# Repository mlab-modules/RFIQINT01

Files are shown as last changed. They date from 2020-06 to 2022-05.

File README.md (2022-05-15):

# RFIQINT01B - RF signal I/Q interface

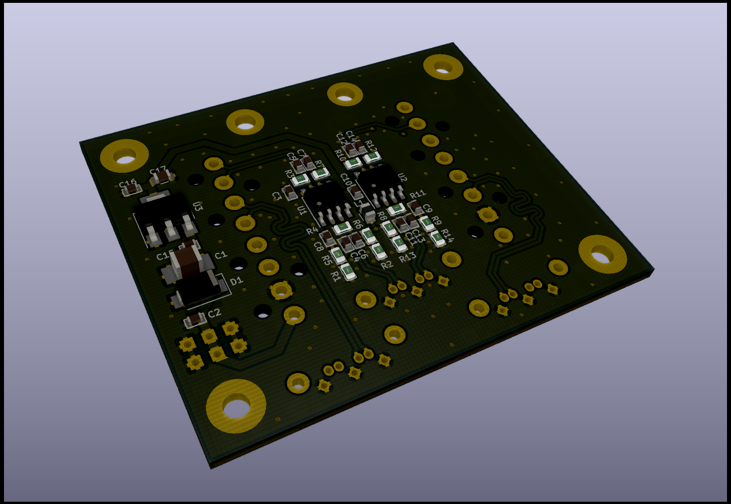
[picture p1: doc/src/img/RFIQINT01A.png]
RFIQINT01B PCB render


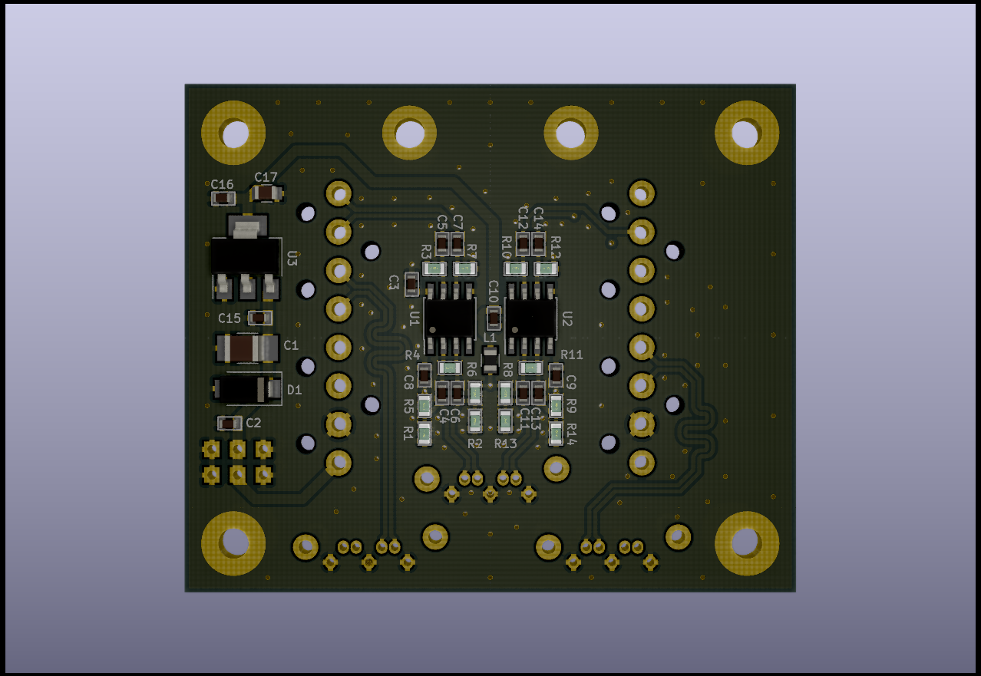
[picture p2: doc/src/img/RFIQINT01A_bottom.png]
RFIQINT01B PCB render


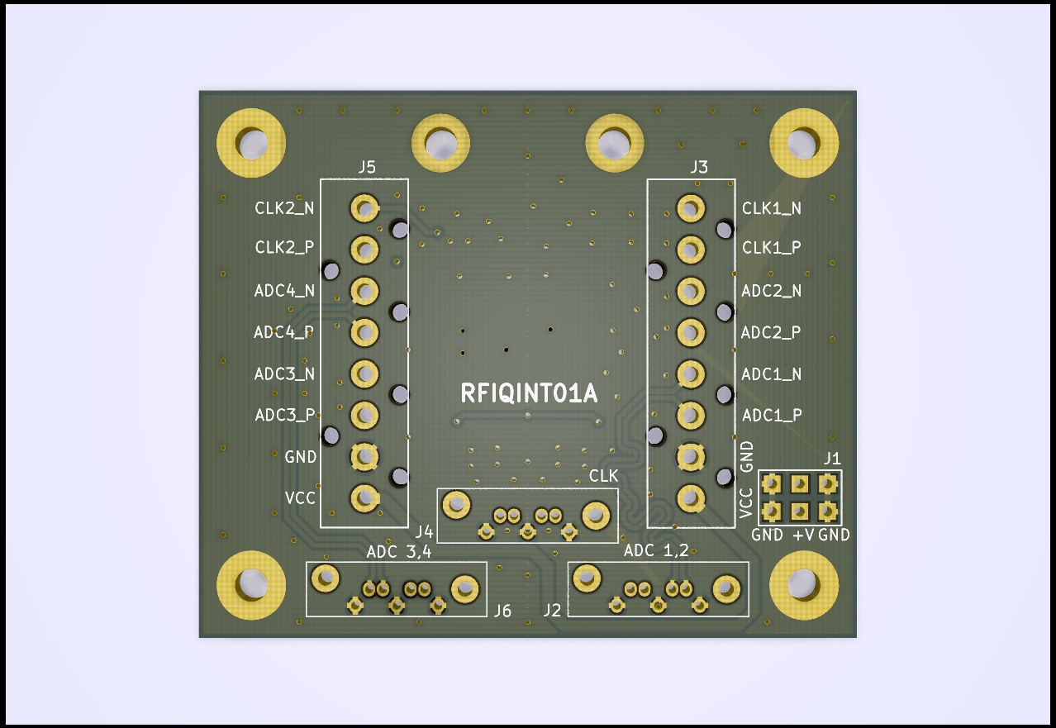
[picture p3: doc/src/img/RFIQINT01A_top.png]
RFIQINT01B PCB render


## Parameters

| Parameter | Value | Description |
|---|---|---|
| Frequency range | 100 - 1000 MHz |  |
| Interface | RJ45 | CAT 7/A cable is expected |
| Operating and storage temperature | -20 - +30°C |  |
| Operational input voltage for Antenna | 9 - 12 V |  |
| Operational input voltage  | 3.3-3.6 V | 130 mA for LO buffer core |

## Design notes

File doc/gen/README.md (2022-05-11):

# PCB

Board size: 60.45x50.29 mm (2.38x1.98 inches)

- This is the size of the rectangle that contains the board
- Thickness: 1.6 mm (63 mils)
- Material: FR4
- Finish: None
- Layers: 2
- Copper thickness: 35 µm

Solder mask: TOP / BOTTOM

- Color: Green

Silk screen: TOP / BOTTOM

- Color: White

Stackup:

| Name | Type | Color | Thickness | Material | Epsilon_r | Loss tangent |
|---|---|---|---|---|---|---|
| F.SilkS | Top Silk Screen | | | | | |
| F.Paste | Top Solder Paste | | | | | |
| F.Mask | Top Solder Mask | | 10 | | | |
| F.Cu | copper | | 35 | | | |
| dielectric 1 | core | | 1510 | FR4 | 4.5 | 0.02 |
| B.Cu | copper | | 35 | | | |
| B.Mask | Bottom Solder Mask | | 10 | | | |
| B.Paste | Bottom Solder Paste  | | | | | |
| B.SilkS | Bottom Silk Screen | | | | | |

# Important sizes

Clearance: 0.2 mm (8 mils)

Track width: 0.4 mm (16 mils)

- By design rules: 0.2 mm (8 mils)

Drill: 0.4 mm (16 mils)

- Vias: 0.4 mm (16 mils) [Design: 0.3 mm (12 mils)]
- Pads: 0.74 mm (29 mils)

Via: 0.75/0.4 mm (30/16 mils)

- By design rules: 0.4/0.3 mm (16/12 mils)
- Micro via: no [0.2/0.1 mm (8/4 mils)]
- Burried/blind via: no

Outer Annular Ring: 0.35 mm (14 mils)

- By design rules: 0.36 mm (14 mils)

Eurocircuits class: 4C

# General stats

Components count: (SMD/THT)

- Top: 0/6 (THT)
- Bottom: 36/6 (SMD + THT)

Defined tracks:

- 0.2 mm (8 mils)
- 0.3 mm (12 mils)
- 0.4 mm (16 mils)
- 0.5 mm (20 mils)
- 0.6 mm (24 mils)
- 0.7 mm (28 mils)
- 1.0 mm (39 mils)

Used tracks:

- 0.4 mm (16 mils) (562) defined: yes
- 0.6 mm (24 mils) (15) defined: yes
- 1.0 mm (39 mils) (37) defined: yes

Defined vias:

Used vias:

- 0.75/0.4 mm (30/16 mils) (Count: 126, Aspect: 2.1 A) defined: no

Holes (excluding vias):

- 0.74 mm (29 mils) (21)
- 0.89 mm (35 mils) (8)
- 1.35 mm (53 mils) (6)
- 1.4 mm (55 mils) (16)
- 1.6 mm (63 mils) (12)
- 3.0 mm (118 mils) (6)

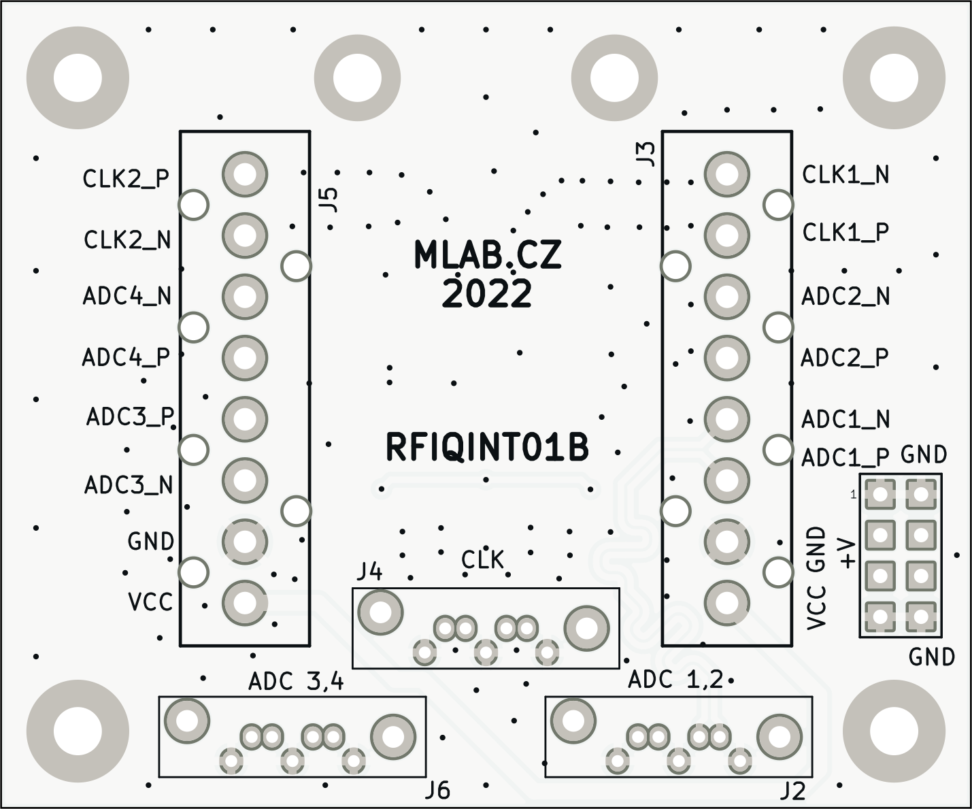
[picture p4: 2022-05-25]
doc/gen/img/RFIQINT01B-top.png

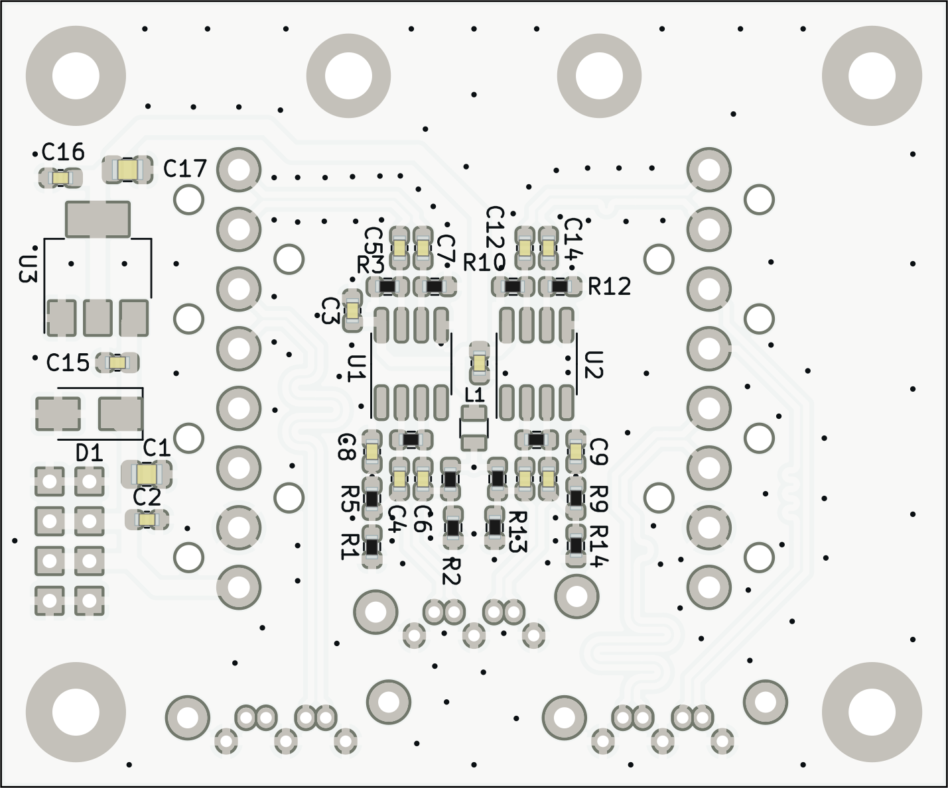
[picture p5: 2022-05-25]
doc/gen/img/RFIQINT01B-bottom.png

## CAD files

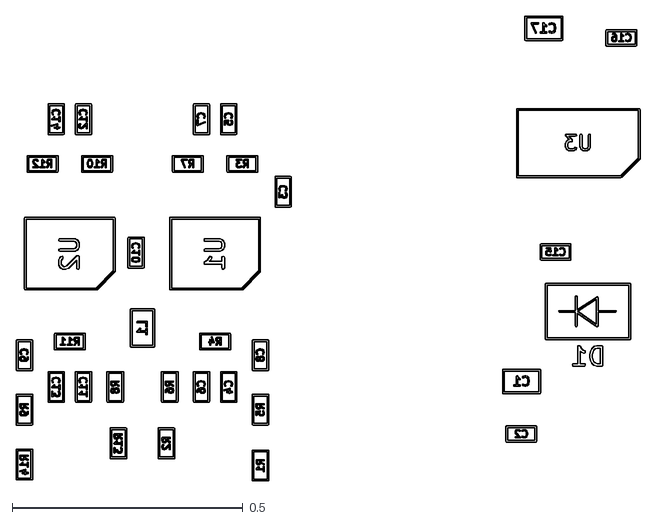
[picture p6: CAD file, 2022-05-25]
doc/gen/dxf/RFIQINT01B-B_Fab.dxf
1.35 x 1.01

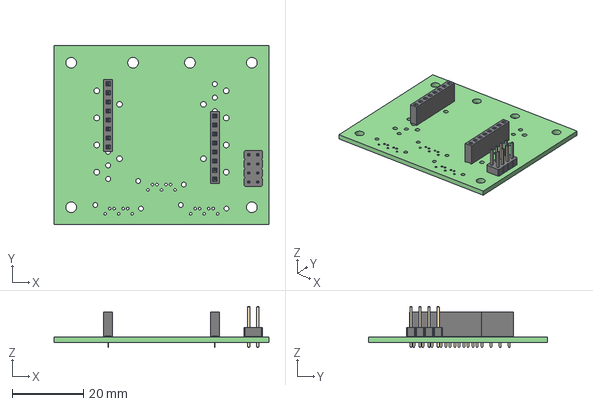
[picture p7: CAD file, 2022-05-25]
doc/gen/RFIQINT01B.step
60.5 x 50.3 x 11.6 mm
tmplr6t_708 PCB

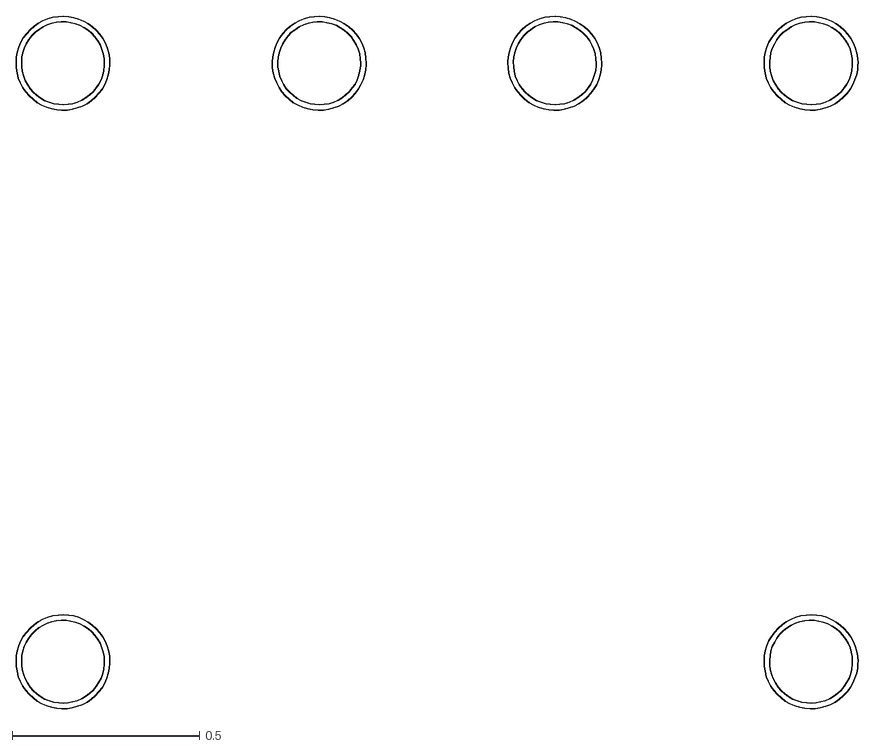
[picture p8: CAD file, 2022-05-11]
doc/gen/dxf/RFIQINT01B-User_Comments.dxf
2.25 x 1.85

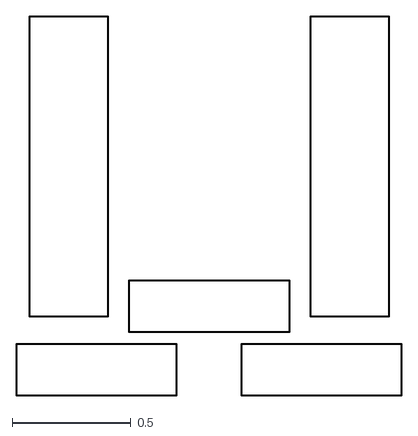
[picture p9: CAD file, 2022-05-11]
doc/gen/dxf/RFIQINT01B-F_Courtyard.dxf
1.62 x 1.59

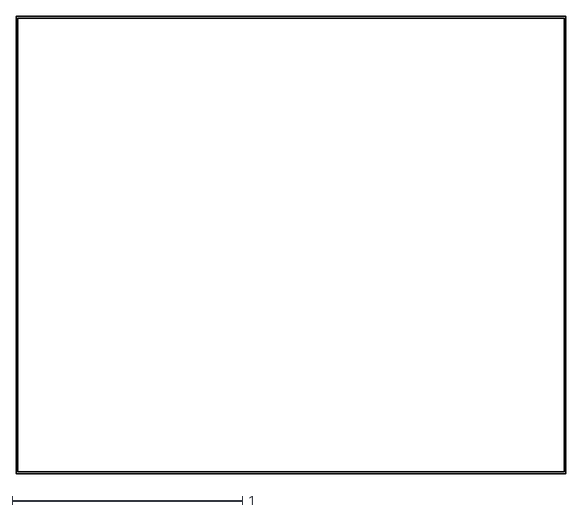
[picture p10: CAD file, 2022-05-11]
doc/gen/dxf/RFIQINT01B-Edge_Cuts.dxf
2.39 x 1.99

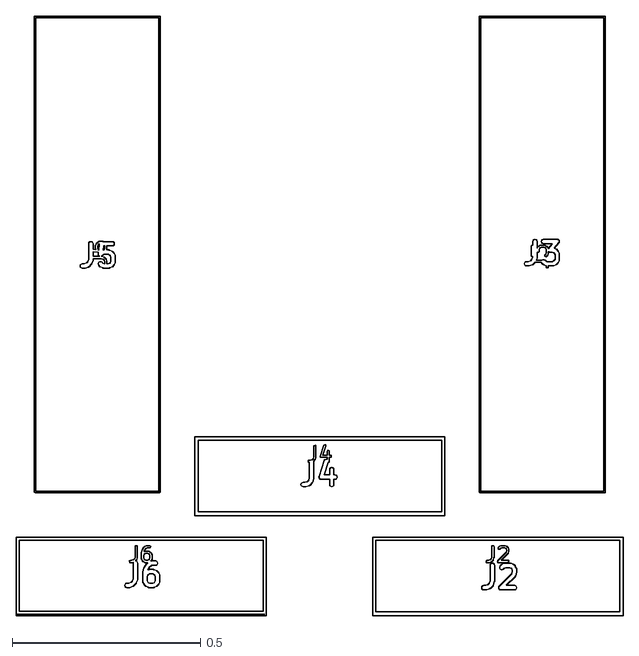
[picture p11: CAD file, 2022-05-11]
doc/gen/dxf/RFIQINT01B-F_Fab.dxf
1.61 x 1.59

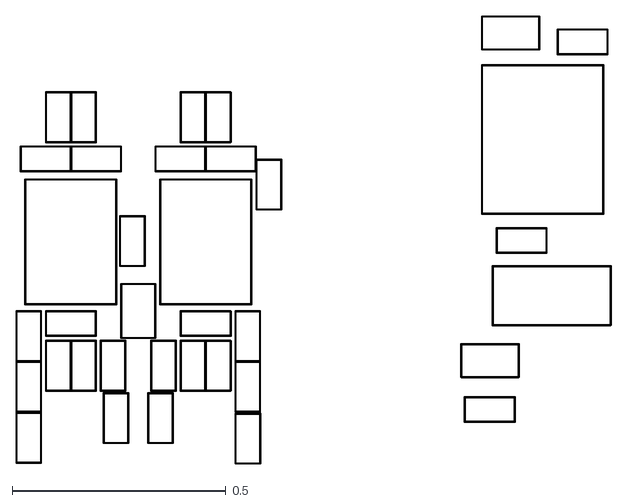
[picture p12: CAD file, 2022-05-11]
doc/gen/dxf/RFIQINT01B-B_Courtyard.dxf
1.39 x 1.05

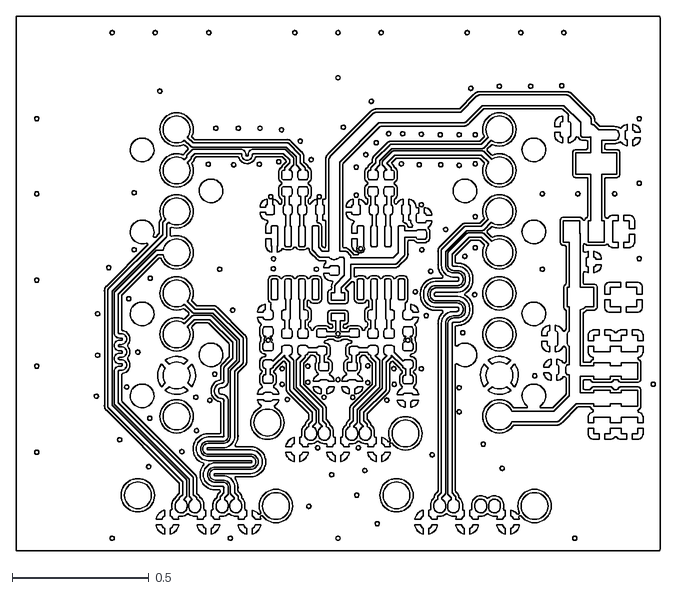
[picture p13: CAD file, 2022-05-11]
doc/gen/dxf/RFIQINT01B-B_Cu.dxf
2.36 x 1.96

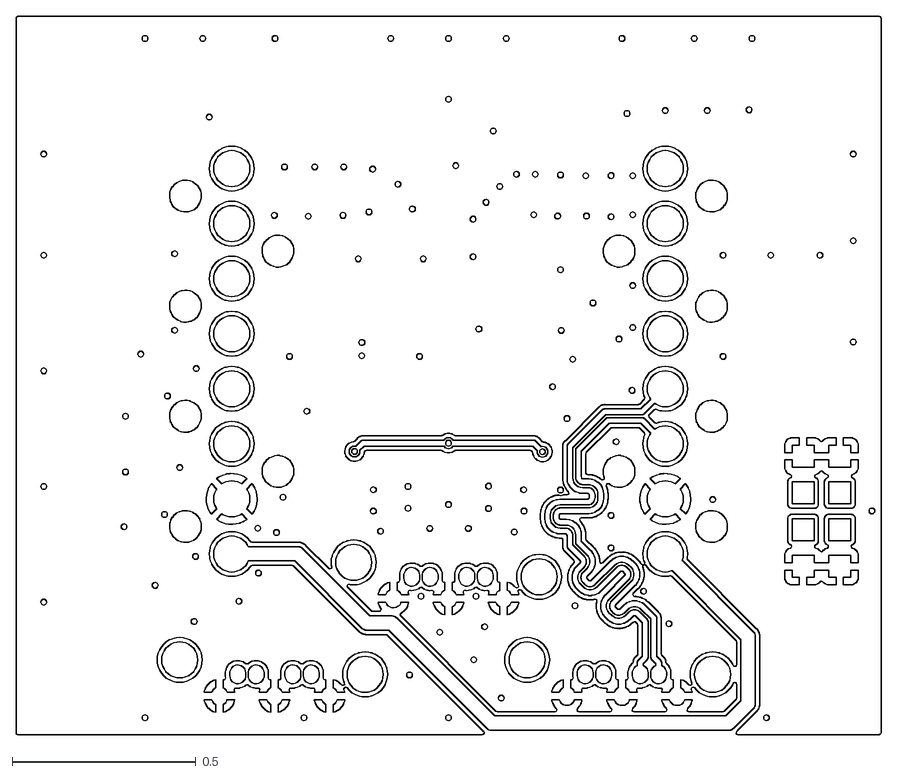
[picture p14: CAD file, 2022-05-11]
doc/gen/dxf/RFIQINT01B-F_Cu.dxf
2.36 x 1.96

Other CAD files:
doc/gen/dxf/RFIQINT01B-F_Adhesive.dxf
doc/gen/dxf/RFIQINT01B-B_Adhesive.dxf
doc/gen/dxf/RFIQINT01B-User_Eco1.dxf
doc/gen/dxf/RFIQINT01B-User_Drawings.dxf
doc/gen/dxf/RFIQINT01B-User_Eco2.dxf
doc/gen/dxf/RFIQINT01B-Margin.dxf
doc/gen/dxf/RFIQINT01B-B_Mask.dxf
doc/gen/dxf/RFIQINT01B-B_Paste.dxf
doc/gen/dxf/RFIQINT01B-B_Silkscreen.dxf
doc/gen/dxf/RFIQINT01B-F_Mask.dxf
doc/gen/dxf/RFIQINT01B-F_Paste.dxf
doc/gen/dxf/RFIQINT01B-F_Silkscreen.dxf

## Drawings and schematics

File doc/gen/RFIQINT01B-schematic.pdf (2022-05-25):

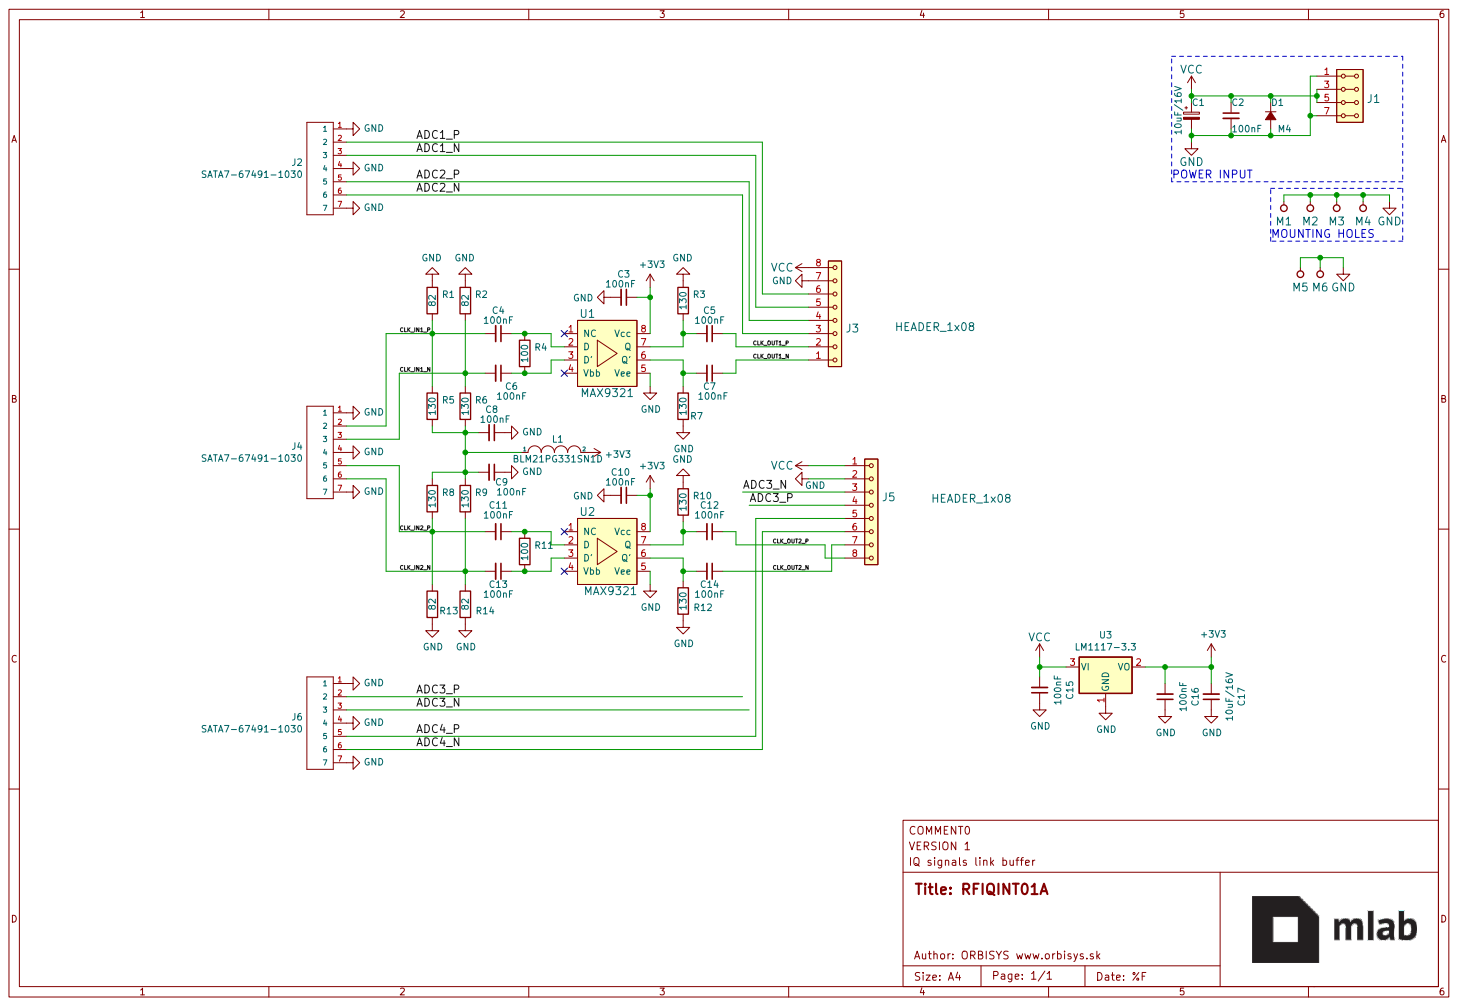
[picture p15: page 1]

COMMENT0 VERSION 1

IQ signals link buffer

Page: 1/1 Date: %F Title: RFIQINT01A | D Author: ORBISYS www.orbisys.sk Size: A4

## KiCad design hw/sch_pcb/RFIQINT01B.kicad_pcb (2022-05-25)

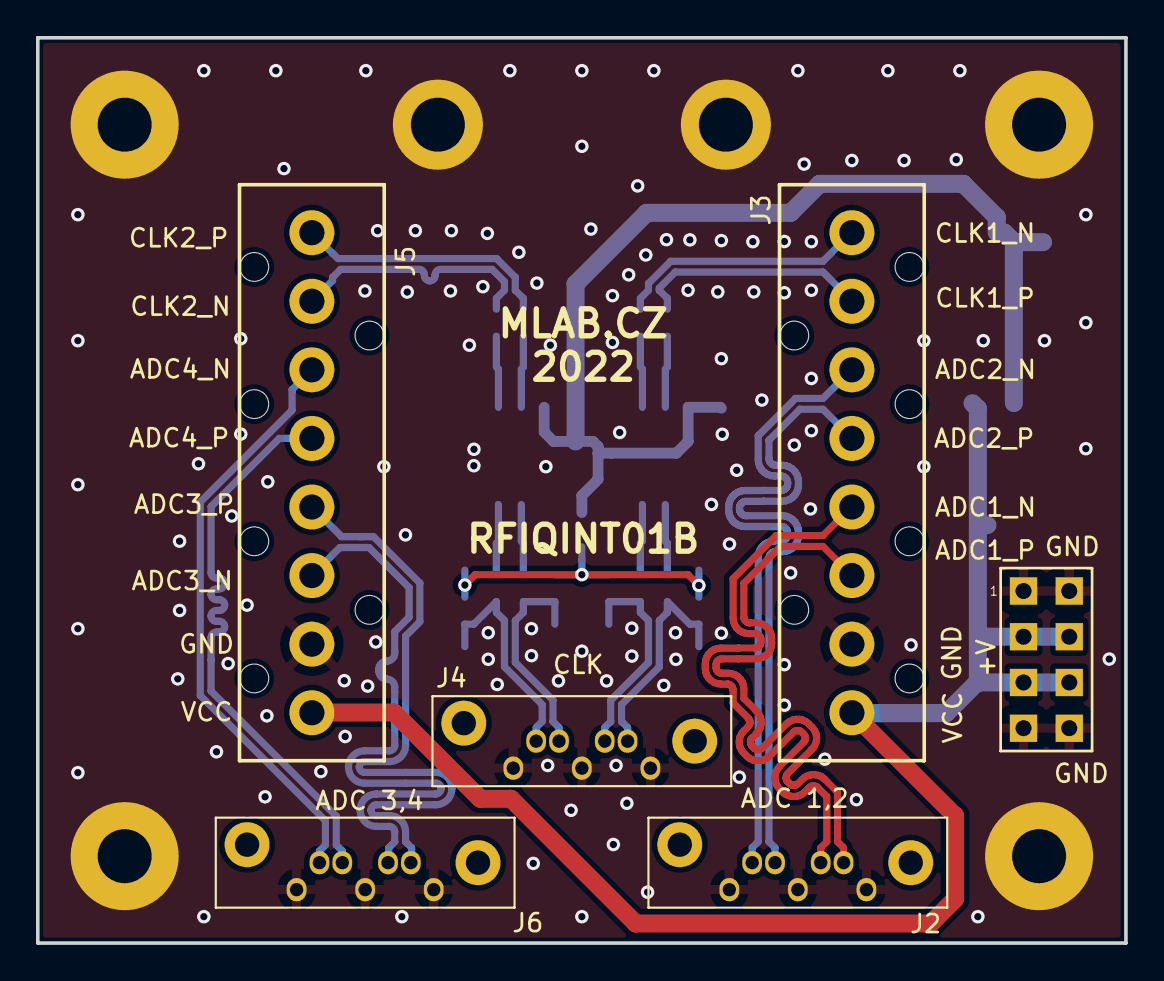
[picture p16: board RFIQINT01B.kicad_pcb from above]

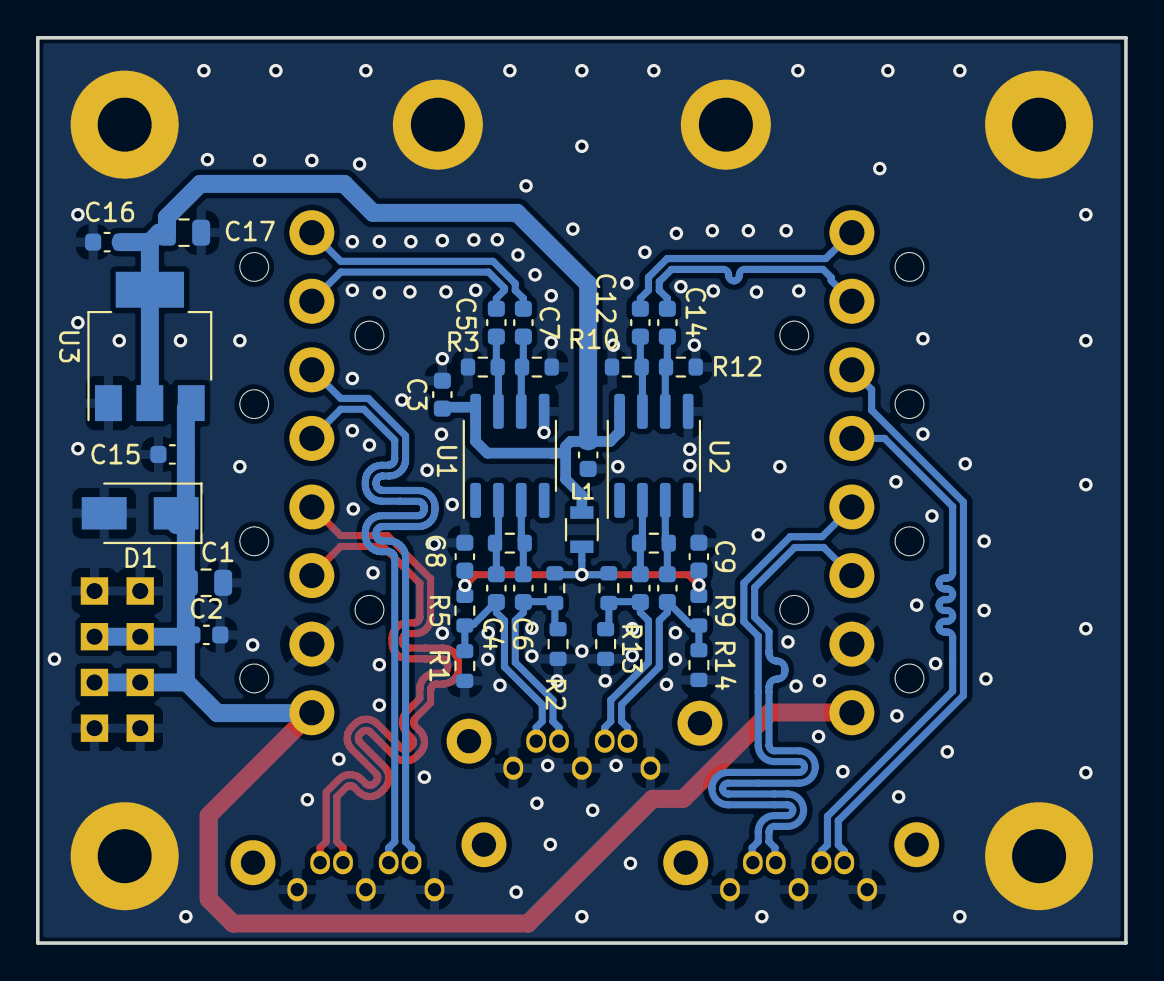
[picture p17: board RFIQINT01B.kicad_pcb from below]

Board: 2 copper layers, 60.5 x 50.3 mm, 48 parts (42 on the bottom side), 28 nets.

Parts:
C1, C17: 10uF/16V; C_0805_2012Metric
C2, C3, C4, C5, C6, C7, C8, C9, C10, C11, C12, C13, C14, C15, C16: 100nF; C_0603_1608Metric
D1: M4; D_SMA
J1: HEADER_2x04_PARALLEL; Straight_2x04
J2, J4, J6: SATA7-67491-1030; SATA-7_THT_VERT_2
J3, J5: HEADER_1x08; IDC381-8-110
L1: BLM21PG331SN1D; L_0805
M1, M2, M3, M4, M5, M6: HOLE; MountingHole_3mm
R1, R2, R13, R14: 82; R_0603_1608Metric
R3, R5, R6, R7, R8, R9, R10, R12: 130; R_0603_1608Metric
R4, R11: 100; R_0603_1608Metric
U1, U2: MAX9321; SOIC-8_3.9x4.9mm_P1.27mm
U3: LM1117-3.3; SOT-223-3_TabPin2

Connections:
+3V3: C3.1, C10.1, C16.2, C17.2, L1.2, U1.8 (Vcc), U2.8 (Vcc), U3.2 (VO)
/ADC1_N: J2.3, J3.5
/ADC1_P: J2.2, J3.6
/ADC2_N: J2.6, J3.3
/ADC2_P: J2.5, J3.4
/ADC3_N: J5.3, J6.3
/ADC3_P: J5.4, J6.2
/ADC4_N: J5.6, J6.6
/ADC4_P: J5.5, J6.5
/CLK_IN1_N: C6.2, J4.3, R2.2, R6.1
/CLK_IN1_P: C4.2, J4.2, R1.2, R5.1
/CLK_IN2_N: C13.2, J4.6, R9.2, R14.1
/CLK_IN2_P: C11.2, J4.5, R8.2, R13.1
/CLK_OUT1_N: C7.1, J3.1
/CLK_OUT1_P: C5.1, J3.2
/CLK_OUT2_N: C14.1, J5.7
/CLK_OUT2_P: C12.1, J5.8
GND: C1.2, C2.2, C3.2, C8.1, C9.1, C10.2, C15.1, C16.1, C17.1, D1.2 (A), J1.1, J1.2, J1.7, J1.8, J2.1, J2.4, J2.7, J3.7, J4.1, J4.4, J4.7, J5.2, J6.1, J6.4, J6.7, M1.1, M2.1, M3.1, M4.1, M5.1, M6.1, R1.1, R2.1, R3.1, R7.2, R10.1, R12.2, R13.2, R14.2, U1.5 (Vee), U2.5 (Vee), U3.1 (GND)
unnamed: C4.1, R4.1, U1.2 (D)
unnamed: C5.2, R3.2, U1.7 (Q)
unnamed: C6.1, R4.2, U1.3 (D')
unnamed: C7.2, R7.1, U1.6 (Q')
unnamed: C8.2, C9.2, L1.1, R5.2, R6.2, R8.1, R9.1
unnamed: C11.1, R11.1, U2.2 (D)
unnamed: C12.2, R10.2, U2.7 (Q)
unnamed: C13.1, R11.2, U2.3 (D')
unnamed: C14.2, R12.1, U2.6 (Q')
VCC: C1.1, C2.1, C15.2, D1.1 (K), J1.3, J1.4, J1.5, J1.6, J3.8, J5.1, U3.3 (VI)

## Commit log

2020-06-15 Initial design.
    [RFIQINT01A.kicad_pcb, RFIQINT01A.sch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]
2022-03-08 Ulozeni v novem formatu KiCAD. A smazani starych dat.
    [RFIQINT01A.kicad_pcb, RFIQINT01A.kicad_sch, RFIQINT01A.sch]
2022-03-08 Prejmenovani kicad projektu
    [RFIQINT01B.kicad_pcb, RFIQINT01B.kicad_sch]
2022-03-08 Edit. #3 #2
    [RFIQINT01B.csv, RFIQINT01B.kicad_pcb, RFIQINT01B.kicad_sch]
2022-03-09 Update title block. Adding link to the datasheet.
    [RFIQINT01B.kicad_sch]
2022-03-10 Fix differential pair routing #3.
    [RFIQINT01B.kicad_pcb, RFIQINT01B.kicad_sch]
2022-05-06 Edit PCB
    [RFIQINT01B.csv, RFIQINT01B.kicad_pcb]
2022-05-11 Update actions products
    [RFIQINT01B-B_Adhesive.dxf, RFIQINT01B-B_Courtyard.dxf, RFIQINT01B-B_Cu.dxf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]
2022-05-25 Editace podkladu pro osazovani
    [RFIQINT01B.kicad_pcb, RFIQINT01B.kicad_sch]
